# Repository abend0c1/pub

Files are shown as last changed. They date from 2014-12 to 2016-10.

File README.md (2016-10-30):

PUB! Programmable USB Button
============================
Program a button to send keystrokes to your computer

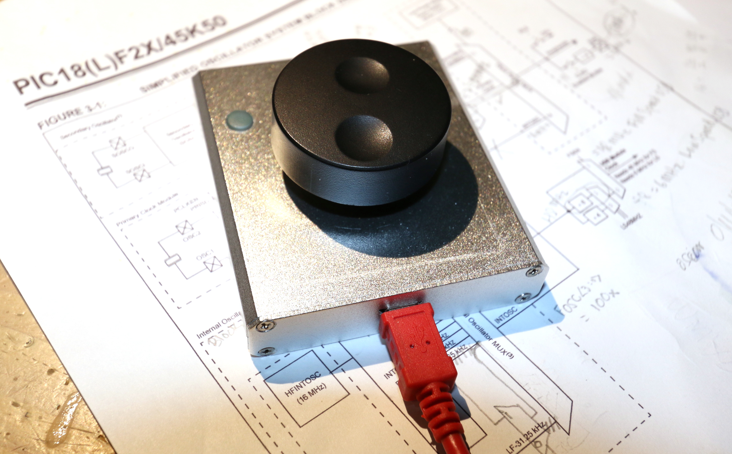
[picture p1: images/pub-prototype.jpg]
prototype


PUB! is a Programmable USB Button on which you can program a sequence of keystrokes. When you press the button those keystrokes are "replayed" over a USB connection.

The button (really a rotary encoder with a built-in push button switch) is programmed using an innovative and slightly quirky interface that does not require any custom software to be installed on your computer. All you need is a text editor like Notepad or gedit.

Features
--------
- One-button design (a rotary encoder with a built in switch).
- Programmed by using an ordinary text editor as a display (for example, gedit on Linux, or Notepad on Windows).
- Up to 127 keystrokes can be recorded and played back.
- Support for conditional logic. For example, Compare to value, Jump on zero, etc.
- Support for 256 x 8-bit "registers" to record state.
- Support for basic arithmetic. Add, subtract, etc.
- Can send USB System Control codes (Power off, sleep, wake) to your PC
- Can send USB Consumer Device functions (e.g. Mute, Play, Pause, Stop, etc.)
- Requires NO drivers (or custom software) for Windows/Linux etc

Futures
-------
The possibilities are fairly broad including:
- Using a Bluetooth module to detect proximity of the button owner's mobile phone so that the USB button is only enabled when its owner is near.
- Addition of an external EEPROM for extra keystroke capacity.
- The one-button user interface could be improved to make it easier to use.

Construction
------------

See http://www.instructables.com/id/PUB-Programmable-USB-Button/

How To Use
----------
### You want to program your password onto the PUB! button
  - Open a text editing program (for example, gedit or Notepad) and make sure it has keyboard focus
  - Plug PUB! into a host USB port
  - By default it is in RUN mode, so press and hold the rotary encoder knob for more than 1 second to switch to PROGRAM mode. It will display in your text editor:

          PUB! Programmable USB Button v0.93
          Main:   Turn=Select, Press=OK, Press+Turn=Set At, Press+Hold=Exit
             0    Set Keystroke at 00
          At Code Action

  - Press the rotary knob to set a keystroke. It will display:

          PUB! Programmable USB Button v0.93
          Key:    Turn=Select, Press+Turn=Modify, Press=OK, Press+Hold=Return
          00 0004 a
          At Code Action

  - Turn the rotary knob to choose the first letter of your password (say c) and then press the knob to add it to the list of actions:

          PUB! Programmable USB Button v0.93
          Key:    Turn=Select, Press+Turn=Modify, Press=OK, Press+Hold=Return
          01 0006 c
          At Code Action
          00 0006 c

  - Continue choosing and adding the remaining letters (say, a and t):

          PUB! Programmable USB Button v0.93
          Key:    Turn=Select, Press+Turn=Modify, Press=OK, Press+Hold=Return
          03 0017 t
          At Code Action
          00 0006 c
          01 0004 a
          02 0017 t

  - Press and hold the rotary knob to Return to the main menu:

          PUB! Programmable USB Button v0.93
          Main:   Turn=Select, Press=OK, Press+Turn=Set At, Press+Hold=Exit
             0    Set Keystroke at 03
          At Code Action
          00 0006 c
          01 0004 a
          02 0017 t

  - Rotate the knob until "Do Local Function" is displayed:

          PUB! Programmable USB Button v0.93
          Main:   Turn=Select, Press=OK, Press+Turn=Set At, Press+Hold=Exit
             0    Do Local Function at 03
          At Code Action
          00 0006 c
          01 0004 a
          02 0017 t

  - Press the knob to enter the "Do" menu:

            PUB! Programmable USB Button v0.93
            Do:     Turn=Modify, Press=OK, Press+Turn=Set At, Press+Hold=Exit
               0    Delete action at 00
            At Code Action
            00 0006 c
            01 0004 a
            02 0017 t

  - Press-and-rotate the knob anticlockwise until "Save to EEPROM" is displayed:

          PUB! Programmable USB Button v0.93
          Do:     Turn=Modify, Press+Turn=Select, Press=OK, Press+Hold=Return
                  Save to EEPROM
          At Code Action
          00 0006 c
          01 0004 a
          02 0017 t

  - Press the knob to save "cat" to the EEPROM

          Saved in EEPROM

  - The device is now in RUN mode. Press the knob to "play" the recorded sequence:

          cat

### An example of some conditional logic

  - Enter the following program into the PUB! device:

          At Code Action
          00 E005 Let W = 05
          01 E200 Put W in R00
          02 0006 c
          03 0004 a
          04 0017 t
          05 002C Space
          06 E500 Say R00
          07 0028 Enter
          08 EF01 Wait 1 sec
          09 E801 Let W = W - 01
          0A F701 Jump if Not Zero to 01

  - Now when you press the knob in run mode you should see the following displayed (1 second wait between lines):

          cat 05
          cat 04
          cat 03
          cat 02
          cat 01

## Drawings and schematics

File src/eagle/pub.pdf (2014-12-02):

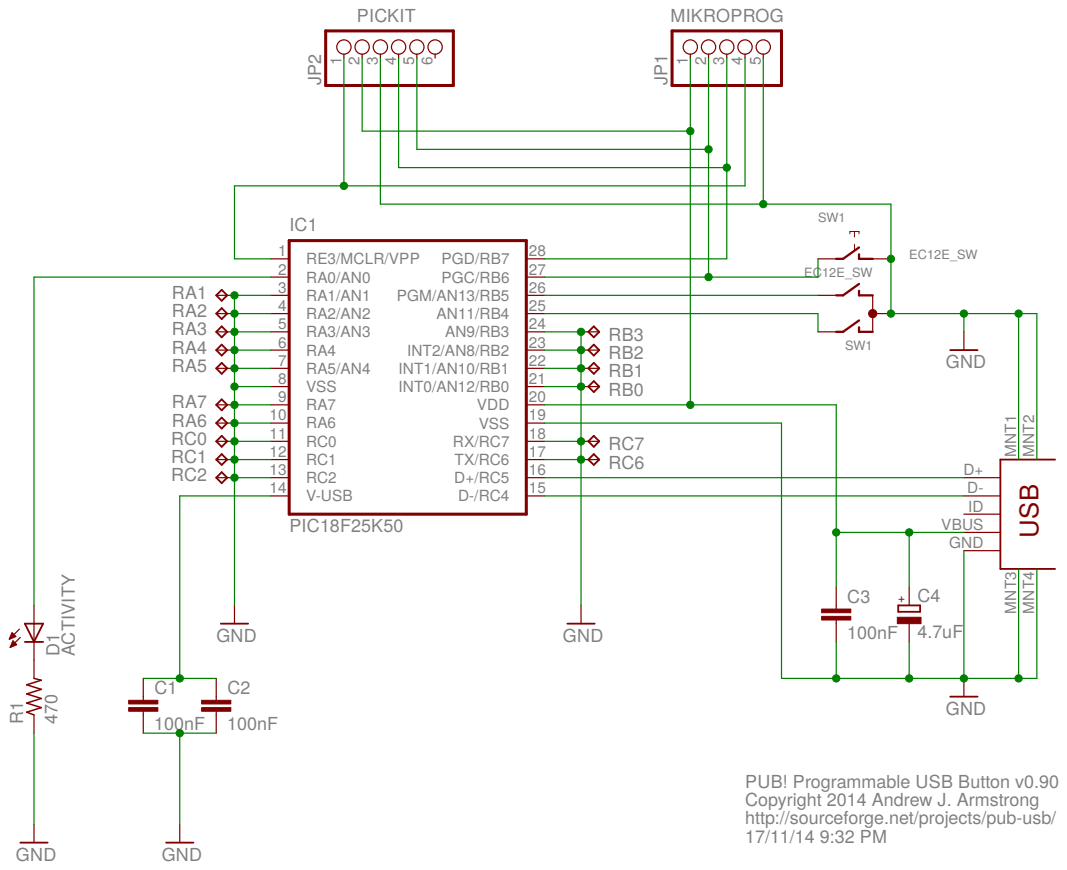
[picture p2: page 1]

PUB! Programmable USB Button v0.90
Copyright 2014 Andrew J. Armstrong
http://sourceforge.net/projects/pub-usb/

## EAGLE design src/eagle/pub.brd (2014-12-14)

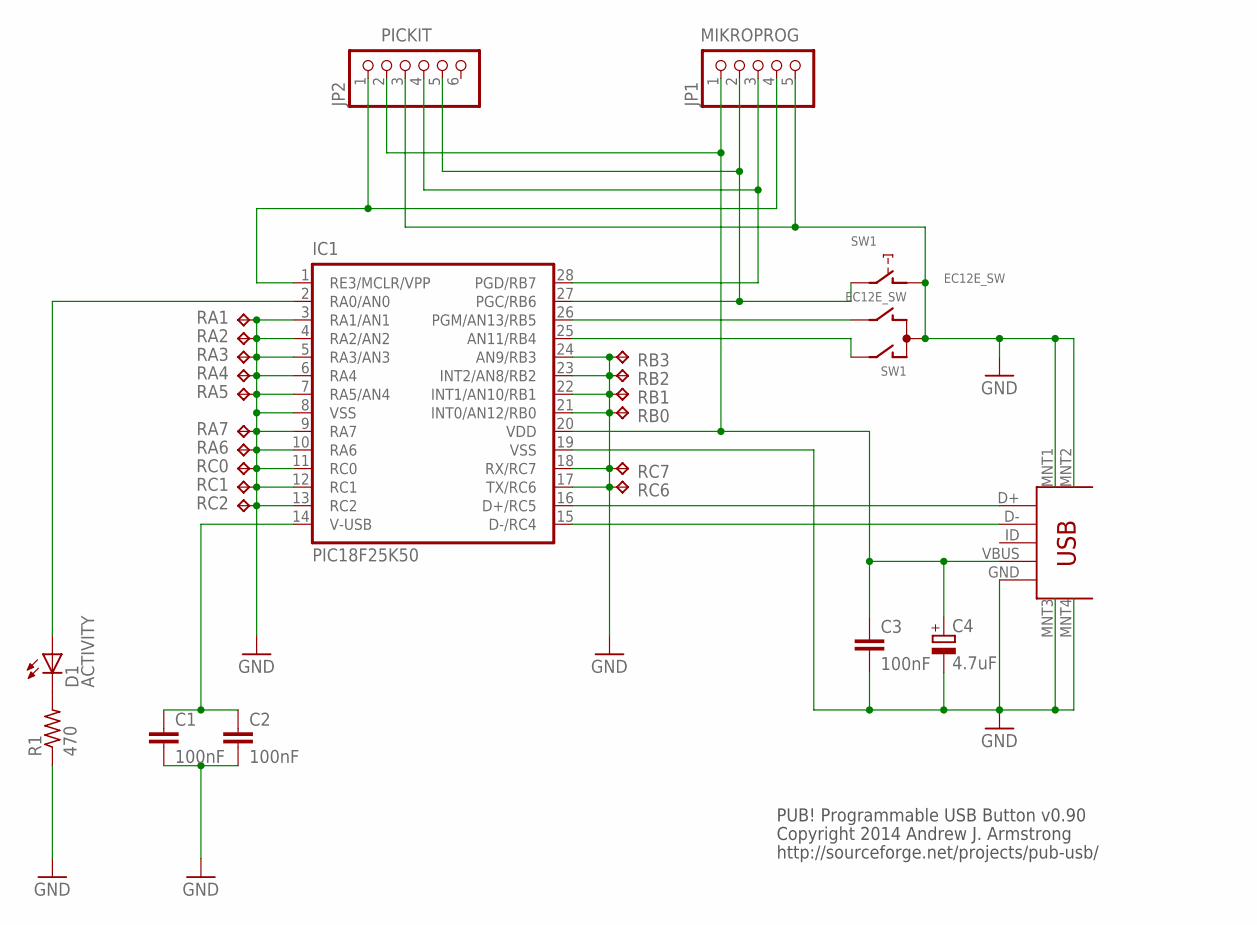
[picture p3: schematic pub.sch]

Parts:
C1, C2, C3: 100nF; C0805
C4: 4.7uF; SMC_A
D1: ACTIVITY; SML1206
IC1: PIC18F25K50; SO28W
JP1: MIKROPROG; 1X05/90
JP2: PICKIT; 1X06/90
JP3: USB-MINIB-5PIN; USB-MINIB
R1: 470; M1206
RA1, RA2, RA3, RA4, RA5, RA6, RA7: TPB1,27; B1,27
RB0, RB1, RB2, RB3: TPB1,27; B1,27
RC0, RC1, RC2, RC6, RC7: TPB1,27; B1,27
SW1: EC12E_SW; ALPS_EC12E_SW

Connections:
GND: C1.2, C2.2, C3.2, C4.-, IC1.3 (RA1/AN1), IC1.4 (RA2/AN2), IC1.5 (RA3/AN3), IC1.6 (RA4), IC1.7 (RA5/AN4), IC1.8 (VSS), IC1.9 (RA7), IC1.10 (RA6), IC1.11 (RC0), IC1.12 (RC1), IC1.13 (RC2), IC1.17 (TX/RC6), IC1.18 (RX/RC7), IC1.19 (VSS), IC1.21 (INT0/AN12/RB0), IC1.22 (INT1/AN10/RB1), IC1.23 (INT2/AN8/RB2), IC1.24 (AN9/RB3), JP1.5, JP2.3, JP3.GND, JP3.MNT1, JP3.MNT2, JP3.MNT3, JP3.MNT4, R1.1, RA1.TP, RA2.TP, RA3.TP, RA4.TP, RA5.TP, RA6.TP, RA7.TP, RB0.TP, RB1.TP, RB2.TP, RB3.TP, RC0.TP, RC1.TP, RC2.TP, RC6.TP, RC7.TP, SW1.C, SW1.D (1)
unnamed: IC1.26 (PGM/AN13/RB5), SW1.B
unnamed: IC1.25 (AN11/RB4), SW1.A
unnamed: C1.1, C2.1, IC1.14 (V-USB)
unnamed: D1.A, IC1.2 (RA0/AN0)
unnamed: IC1.16 (D+/RC5), JP3.D+
unnamed: IC1.15 (D-/RC4), JP3.D-
unnamed: C3.1, C4.+, IC1.20 (VDD), JP1.1, JP2.2, JP3.VBUS
unnamed: IC1.27 (PGC/RB6), JP1.2, JP2.5, SW1.E (2)
unnamed: IC1.28 (PGD/RB7), JP1.3, JP2.4
unnamed: IC1.1 (RE3/MCLR/VPP), JP1.4, JP2.1
unnamed: D1.C, R1.2

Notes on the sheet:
Copyright 2014 Andrew J. Armstrong
http://sourceforge.net/projects/pub-usb/
PUB! Programmable USB Button v0.90

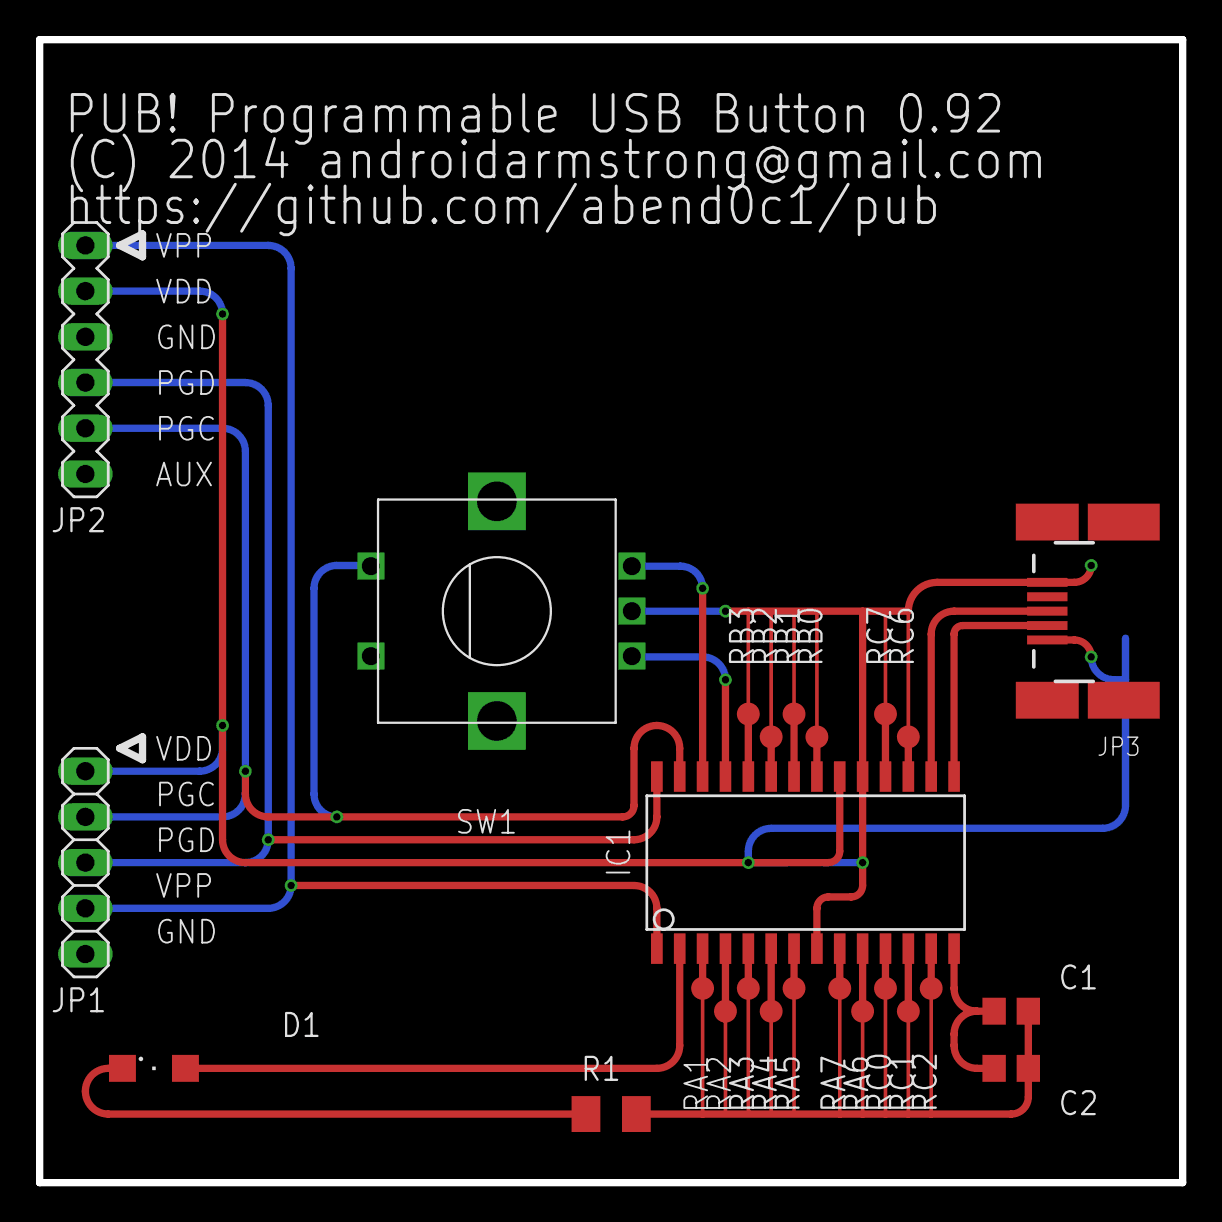
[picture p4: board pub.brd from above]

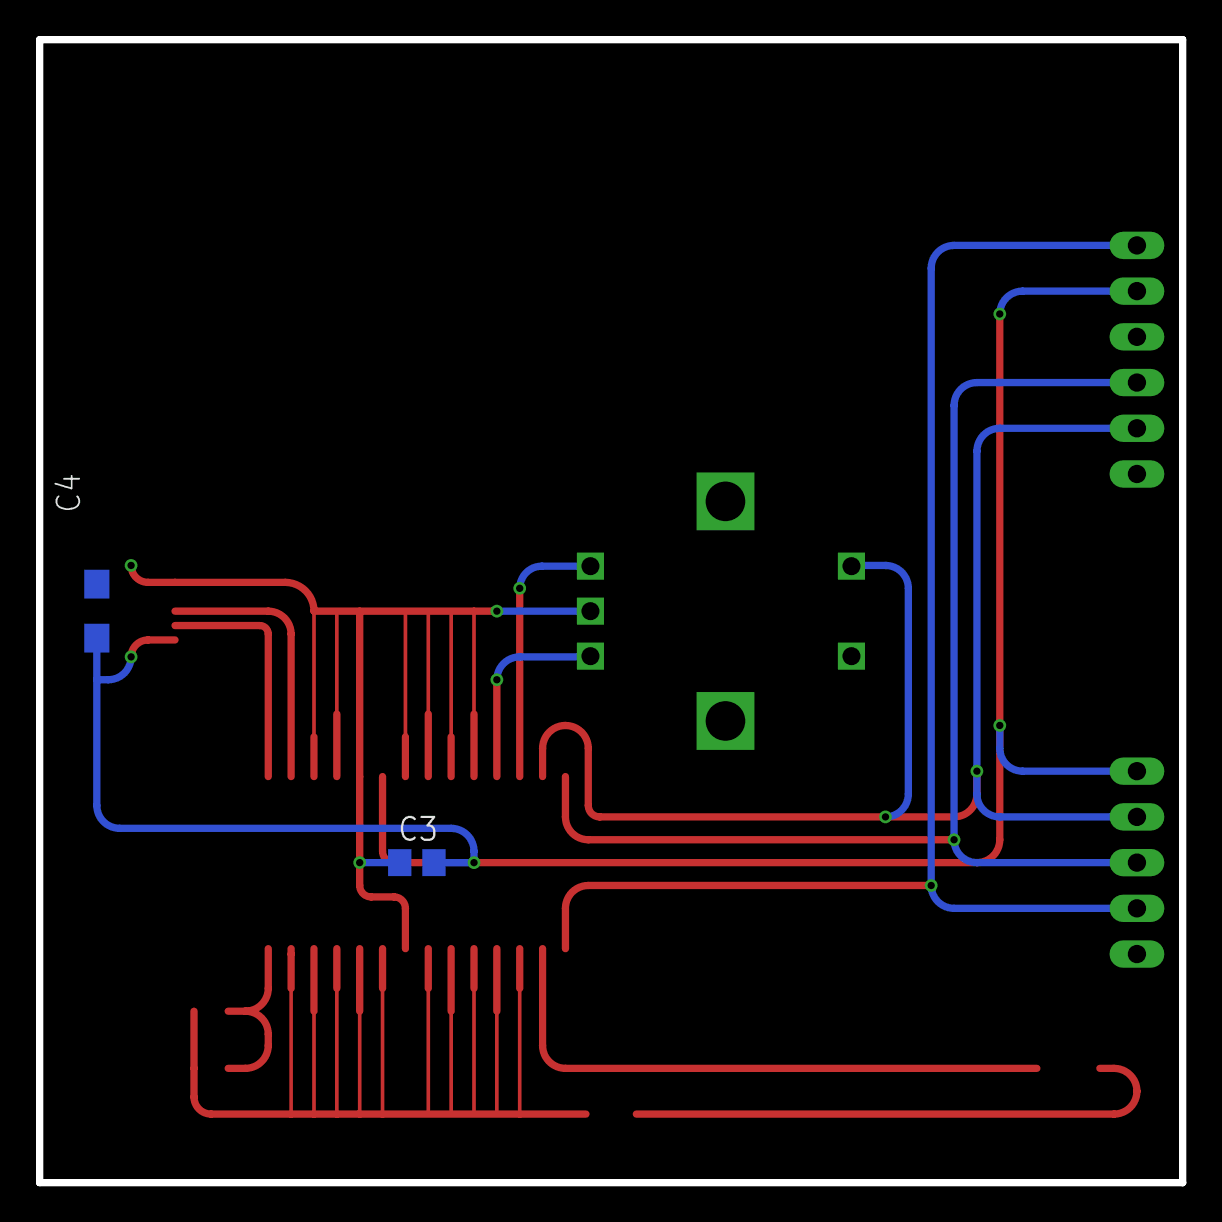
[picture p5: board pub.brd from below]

Board: 2 copper layers, 63.5 x 63.5 mm, 28 parts (2 on the bottom side), 12 nets.

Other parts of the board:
U$1: LIGHTGUIDE

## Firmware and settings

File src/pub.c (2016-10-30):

/*
  PUB! Programmable USB Button
  Copyright (C) 2014 Andrew J. Armstrong

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
  You should have received a copy of the GNU General Public License
  along with this program; if not, write to the Free Software
  Foundation, Inc., 59 Temple Place, Suite 330, Boston, MA
  02111-1307  USA

  Author:
  Andrew J. Armstrong <androidarmstrong@gmail.com>

*/

/*
-------------------------------------------------------------------------------

NAME     - PUB! Programmable USB Button

FUNCTION - This is a programmable button on which you can record a sequence of
           keystrokes (and/or other USB functions) and then play that sequence
           back when you press it.

FEATURES - 1. A single rotary encoder knob (with push switch) is the only input.
           2. Can record and replay up to 127 keystrokes (or other "actions").
           3. Absolutely NO HOST DRIVERS required.

PIN USAGE -                     PIC18F25K50
                           .------------------.                       .--IOC
            MCLR       --> | RE3  1    28 RB7 | <-- PGD               ||
            LED        <-- | RA0  2    27 RB6 | <-- PGC, Rotary button||
                       <-- | RA1  3    26 RB5 | <-- Rotary B          || PORTB
                       <-- | RA2  4    25 RB4 | <-- Rotary A          || Weak
                       <-- | RA3  5    24 RB3 | <--                    | Pullups
                       <-- | RA4  6    23 RB2 | <--                    | Enabled
                       <-- | RA5  7    22 RB1 | <--                    |
            Ground     --- | VSS  8    21 RB0 | <--                    |
            n/c        --- | RA7  9    20 VDD | --- +5V
                       <-- | RA6  10   19 VSS | --- Ground
                       <-- | RC0  11   18 RC7 | --> RX
                       <-- | RC1  12   17 RC6 | --> TX
                       <-- | RC2  13   16 RC5 | <-> USB D+
            2 x 100 nF --- | VUSB 14   15 RC4 | <-> USB D-
                           '------------------'

            Rotary Encoder with switch (e.g. ALPS EC11K0924401):

                            .-------.
             Rotary A   <-- |A     D|--> Rotary button
             Ground     <-- |C  o / |
             Rotary B   <-- |B     E|--> Ground
                            '-------'

CONFIG    - The PIC18F25K50 configuration fuses should be set as follows (items
            marked with '*' are essential for this program to operate correctly):

            CONFIG1L 2B 00101011
                          1      = *LS48MHZ: System clock is expected at 48 MHz, FS/LS USB clock divide-by is set to 8
                           01    = *CPUDIV: CPU system clock (48 MHz) divided by 2 (= 24 MHZ)
                             0   =  Unimplemented
                              x  =  CFGPLLEN: (ignored, set dynamically)
                               x =  PLLSEL: (ignored, set dynamically)
            CONFIG1H 28 00101000
                        0        =  IESO: Oscillator Switchover mode disabled
                         0       =  FCMEN: Fail-Safe Clock Monitor disabled
                          1      = *PCLKEN: Primary Clock is always enabled
                           0     =  Unimplemented
                            1000 = *FOSC: Internal oscillator block
            CONFIG2L 5F 01011111
                        0        =  Unimplemented
                         1       =  LPBOR: Low-Power Brown-out Reset disabled
                          0      =  Unimplemented
                           11    =  BORV: VBOR set to 1.9V nominal
                             11  =  BOREN: Brown-out Reset enabled in hardware only (SBOREN is disabled)
                               1 =  PWRTEN: Power-up Timer disabled
            CONFIG2H 3C 00111100
                        00       =  Unimplemented
                          1111   =  WDTPS: Watchdog Timer Postscale Select = 1:32768
                              00 =  WDTEN: Watchdog Timer disabled in hardware, SWDTEN bit disabled
            CONFIG3L 00 00000000
                        00000000 =  Unimplemented
            CONFIG3H 53 01010000
                        0        = *MCLRE: RE3 input pin enabled; MCLR disabled
                         1       =  SDOMX: SDO is on RB3
                          0      =  Unimplemented
                           1     =  T3CMX: T3CKI is on RC0
                            00   =  Unimplemented
                              0  =  PDADEN: ANSELB<5:0> resets to 0, PORTB<4:0> pins are configured as digital I/O on Reset
                               0 =  CCP2MX: CCP2 input/output is multiplexed with RB3
            CONFIG4L 81 10000001 =  Default
            CONFIG5L 0F 00001111 =  Default
            CONFIG5H C0 11000000 =  Default
            CONFIG6L 0F 00001111 =  Default

OPERATION - The user interacts with the system via a digital encoder knob with
            a built-in switch and, when in PROGRAM mode, with a host-based text
            editor program than understands fairly standard editing control
            sequences.

            In RUN mode (the default mode when the device is plugged into a USB
            port) the user simply presses the rotary knob to cause the previously
            programmed sequence of keystrokes to be sent to the host over the
            connecting USB cable.

            If the user presses the knob down for more than about 3 seconds,
            then the device enters PROGRAM mode. The user must already
            have started and given focus to the above-mentioned text editor
            host application because this will be the means of communication
            with the user. If that is not done then the device will inject
            unwanted keystrokes into the application that currently has the
            keyboard focus.

            - Start a text editor program on the host computer and ensure it
              has keyboard focus.

            - Press and hold the rotary encoder to enter PROGRAM mode.
              The following prompt will be keyed into the text editor:

              PUB! Programmable USB Button vn.nn
              Main:   Turn=Select, Press=OK, Press+Turn=Set At, Press+Hold=Exit
                 0    Set Keystroke at 00

              At Code Action

            - Rotate the knob to choose between the available menu functions
              which are currently:

              Set Keystroke
              Set System Control function
              Set Consumer Device function
              Set Local Function (WAIT, GOTO etc)
              Save to EEPROM
              Redisplay
              Reload from EEPROM
              Delete Action

            - Press the knob to select the desired function. For example,
              Set Keystroke

            - Rotate the knob until the desired keystroke is displayed:

              00 0004 a

            - For "Set keystroke" you can choose a combination of keystroke
              modifiers (Ctl, Alt, Shift, or GUI) by pressing and holding the
              knob down while rotating it:

              00 0104 SHIFT+A

            - Press the knob to append the displayed keystroke to the list of
              keystrokes (or functions) to be recorded.

            - Select and append more keystrokes as required.

            - Press and hold the knob to return to the main menu.

            - Rotate the knob to choose the "Save to EEPROM" function.

            - Now when you press the knob the saved keystrokes will be replayed.





NOTES    - 1. The source code is written in MikroC Pro from mikroe.com


REFERENCE - USB Human Interface Device Usage Tables at:
            http://www.usb.org/developers/devclass_docs/Hut1_12v2.pdf

            USB Device Class Definition for Human Interface Devices (HID) at:
            http://www.usb.org/developers/devclass_docs/HID1_11.pdf

            USB 2.0 Specification at:
            http://www.usb.org/developers/docs/usb_20_101111.zip
            Specifically, the file in that zip archive called usb_20.pdf

AUTHORS  - Init Name                 Email
           ---- -------------------- ------------------------------------------
           AJA  Andrew J. Armstrong  androidarmstrong@gmail.com

CREDITS  - Rotary encoder logic based on code originally written by Ben Buxton.
           http://www.buxtronix.net/2011/10/rotary-encoders-done-properly.html


HISTORY  - Date     Ver   By  Reason (most recent at the top please)
           -------- ----- --- -------------------------------------------------
           20161030 0.93  AJA Detected the Caps Lock state
           20141130 0.92  AJA Added arithmetic and conditional jump instructions
           20141108 0.91  AJA Fixed PCB to match code. Rotary button on RB6
           20141012 0.90  AJA First published version
           20140817 0.10  AJA Initial development

-------------------------------------------------------------------------------
*/
#include <stdint.h>
#include <built_in.h>
#include "USBdsc.h"
#include "pub.h"

// Copies a text string from ROM into a RAM buffer (saves RAM)
char * _TEXT(const char * p)
{
  static char sText[70];
  char * q;
  for (q=&sText; *q++ = *p++; );
  return &sText;
}

const char * getKeyDescWithNoShift (uint8_t key) // Note: Literals returned as const are in ROM
{ // Keyboard key without SHIFT modifier key pressed
  if (key < ELEMENTS(UNSHIFTED_USB_DESC))
  {
    return UNSHIFTED_USB_DESC[key];
  }
  else
  {
    return "";
  }
}

const char * getKeyDescWithShift(uint8_t key) // Note: Literals returned as const are in ROM
{ // Keyboard key with SHIFT modifier key pressed
  if (key < ELEMENTS(SHIFTED_USB_DESC))
  {
    return SHIFTED_USB_DESC[key];
  }
  else
  {
    return "";
  }
}


const char * getUsageDesc (t_action * pAction) // Note: Literals returned as const are in ROM
{
  switch (pAction->key.page)
  {
    case PAGE_KEYBOARD:
      if (pAction->key.mod & MODIFIER_LEFTSHIFT)
      {
        const char * pKeyDescWithShift = getKeyDescWithShift(pAction->key.usage);
        if (*pKeyDescWithShift)
          return pKeyDescWithShift;
      }
      return getKeyDescWithNoShift(pAction->key.usage);

    case PAGE_SYSTEM_CONTROL:
      if (pAction->sys.usage < ELEMENTS(SYSTEM_CONTROL_DESC))
      {
        return SYSTEM_CONTROL_DESC[pAction->sys.usage];
      }
      else
        return "";

    case PAGE_CONSUMER_DEVICE:
      if (pAction->cons.usage < ELEMENTS(CONSUMER_DEVICE_DESC))
      {
        return CONSUMER_DEVICE_DESC[pAction->cons.usage];
      }
      else
        return "";
//  case 0x30:     // Reserved
//  case 0x40:     // Reserved
//  case 0x50:     // Reserved
//  case 0x60:     // Reserved
//  case 0x70:     // Reserved
//  case 0x90:     // Reserved
//  case 0x90:     // Reserved
//  case 0xA0:     // Reserved
//  case 0xB0:     // Reserved
//  case 0xC0:     // Reserved

    case PAGE_DO:
      switch (pAction->key.mod)
      {
        case DO_DELETE:
          return "Delete action";
        case DO_LOAD:
          return "Load from EEPROM";
        case DO_SAVE:
          return "Save to EEPROM";
        case DO_REDISPLAY:
          return "Redisplay";
        default:
          return "";
      }

    case PAGE_EXECUTE:
      switch (pAction->key.mod)
      {
        case EXECUTE_SET:
          return "Let W = ";
        case EXECUTE_GET:
          return "Get W from R";
        case EXECUTE_PUT:
          return "Put W in R";
        case EXECUTE_COMPARE_IMMEDIATE:
          return "Compare W to ";
        case EXECUTE_COMPARE:
          return "Compare W to R";
        case EXECUTE_SAY:
          return "Say R";
        case EXECUTE_FORMAT:
          return "Say in ";
        case EXECUTE_ADD_IMMEDIATE:
          return "Let W = W + ";
        case EXECUTE_SUB_IMMEDIATE:
          return "Let W = W - ";
        case EXECUTE_CLEAR:
          return "Clear memory to ";
        case EXECUTE_ADD:
          return "Let W = W + R";
        case EXECUTE_SUB:
          return "Let W = W - R";
        case EXECUTE_MUL:
          return "Let W = W x R";
        case EXECUTE_DIV:
          return "Let W = W / R";
        case EXECUTE_WAIT_MS:
          return "Wait "; // milliseconds
        case EXECUTE_WAIT_SEC:
          return "Wait "; // seconds
        default:
          return "";
      }

    case PAGE_JUMP:
      switch (pAction->key.mod)
      {
        case JUMP_RELATIVE:
          return "Jump Relative";
        case JUMP_IF_CARRY:
          return "Jump if Carry";
        case JUMP_IF_HIGH:
          return "Jump if High";
        case JUMP_IF_HIGH_OR_CARRY:
          return "Jump if High or Carry";
        case JUMP_IF_LOW:
          return "Jump if Low";
        case JUMP_IF_LOW_OR_CARRY:
          return "Jump if Low or Carry";
        case JUMP_IF_NOT_ZERO_OR_CARRY:
          return "Jump if Not Zero or Carry";
        case JUMP_IF_NOT_ZERO:
          return "Jump if Not Zero";
        case JUMP_IF_ZERO:
          return "Jump if Zero";
        case JUMP_IF_ZERO_OR_CARRY:
          return "Jump if Zero or Carry";
        case JUMP_IF_NOT_LOW_OR_CARRY:
          return "Jump if Not Low or Carry";
        case JUMP_IF_NOT_LOW:
          return "Jump if Not Low";
        case JUMP_IF_ZERO_OR_LOW:
          return "Jump if Zero or Low";
        case JUMP_IF_NOT_HIGH:
          return "Jump if Not High";
        case JUMP_IF_NOT_CARRY:
          return "Jump if Not Carry";
        case JUMP:
          return "Jump";
        default:
          break;
      }

    default:
      return "";
  }
}

void toPrintableHex(uint8_t c, char * p)
{
  static const char HEX[] = "0123456789ABCDEF";
  *p++ = HEX[(c & 0xF0) >> 4];
  *p++ = HEX[(c & 0x0F)     ];
  *p   = '\0';
}

void adjustShiftModifier ()
{
  if (usbToHost[3] >= USB_KEY_A && usbToHost[3] <= USB_KEY_Z)  // Handle SHIFT for alphabetics
  {
    // If the user wants SHIFT+A to be sent to the host, then it is reasonable
    // to expect it to be interpreted by the host as an uppercase "A". But, if
    // the Caps Lock indicator is on, SHIFT+A would result in the host seeing
    // it as a lowercase "a"...UNLESS we can choose to set the SHIFT modifier
    // depending on the current state of the Caps Lock LED indicator.

    // Truth table:
    // input       input           output
    // modifiers   Caps Lock       modifiers
    // SHIFT bit   LED light       SHIFT bit   Result at host
    // ---------   ---------  -->  ---------   --------------
    //     0           0               0             a
    //     0           1               1             a
    //     1           0               1             A
    //     1           1               0             A
    // This is a classic Exclusive-OR truth table, from which we can code:

    if ((usbToHost[1] & SHIFT) != leds.bits.CapsLock) // Logical Exclusive-OR
      usbToHost[1] |= SHIFT;              // SHIFT modifier bit = 1
    else
      usbToHost[1] &= ~SHIFT;             // SHIFT modifier bit = 0
  }
}


void playSystemControlCommand(t_action * pAction)
{
  if (!bUSBReady) return;
  usbToHost[0] = REPORT_ID_SYSTEM_CONTROL;  // Report Id = System Control
  usbToHost[1] = pAction->sys.usage;        // Function requested
  while(!HID_Write(&usbToHost, 2));         // Copy to USB buffer and try to send
  usbToHost[1] = 0;                         // No function requested anymore
  while(!HID_Write(&usbToHost, 2));         // Copy to USB buffer and try to send
}

void playConsumerDeviceCommand(t_action * pAction)
{
  if (!bUSBReady) return;
  usbToHost[0] = REPORT_ID_CONSUMER_DEVICE; // Report Id = Consumer Device
  usbToHost[1] = pAction->cons.usage;       // Function requested (low byte)
  usbToHost[2] = pAction->cons.usage >> 8;  // Function requested (high byte)
  while(!HID_Write(&usbToHost, 3));         // Copy to USB buffer and try to send
  usbToHost[1] = 0;                         // Function requested low byte
  usbToHost[2] = 0;                         // Function requested high byte
  while(!HID_Write(&usbToHost, 3));         // Copy to USB buffer and try to send
}

void sayNoKeyPressed()
{
  usbToHost[0] = REPORT_ID_KEYBOARD;        // Report Id = Keyboard
  usbToHost[1] = 0;                         // No modifiers now
  usbToHost[3] = 0;                         // No key pressed now
  while(!HID_Write(&usbToHost, 4));         // Copy to USB buffer and try to send
}

void playKeystroke(t_action * pAction)
{
  if (!bUSBReady) return;
  if (usbToHost[0] == REPORT_ID_KEYBOARD && // If new keystroke is the same as the last one
      usbToHost[1] == pAction->key.mod   &&
      usbToHost[3] == pAction->key.usage)
  {
    sayNoKeyPressed();                      // Release the key before sending it again
  }
  usbToHost[0] = REPORT_ID_KEYBOARD;        // Report Id = Keyboard
  usbToHost[1] = pAction->key.mod;          // Ctrl/Alt/Shift modifiers
  usbToHost[2] = 0;                         // Reserved for OEM
  usbToHost[3] = pAction->key.usage;        // Key pressed
  adjustShiftModifier();                    // Adjust SHIFT for alphabetics
  while(!HID_Write(&usbToHost, 4));         // Copy to USB buffer and try to send
  usbToHost[1] = pAction->key.mod;          // Reset modifiers to what was requested
}

void say(uint8_t * p)
{
  uint8_t c;
  t_action action;

  while (*p)
  {
    if (*p < sizeof(ASCII_to_USB))
    {
      c = ASCII_to_USB[*p]; // Top bit on means capitalise with Left Shift
    }
    else
    {
      c = SPACE; // Replace invalid ASCII character with a space
    }
    if (c & 0b10000000) // If SHIFT key needed
    {
      action.key.mod = MODIFIER_LEFTSHIFT;
      action.key.usage = c & 0b01111111;
    }
    else
    {
      action.key.mod = 0;
      action.key.usage = c;
    }
    playKeystroke(&action);
    p++;
  }
  sayNoKeyPressed(); // Release key otherwise the host will think the last key is still being pressed
}

void sayConst(const uint8_t * p)
{
  say(_TEXT(p));
}

void sayModifiers(t_keyboardAction * pAction)
{
  if (pAction->mod & MODIFIER_LEFTGUI)     sayConst("GUI+");
  if (pAction->mod & MODIFIER_LEFTCTL)     sayConst("CTL+");
  if (pAction->mod & MODIFIER_LEFTALT)     sayConst("ALT+");
  if (pAction->mod & MODIFIER_LEFTSHIFT)   sayConst("SHIFT+");
}

void sayChar(uint8_t c)
{
  char sString[2];
  sString[0] = c;
  sString[1] = '\0';
  say(sString);
}

void sayHex(uint8_t c)
{
  char xString[3];
  toPrintableHex(c, xString);
  say(xString);
}

void sayDec(uint8_t c)
{
  char * p;
  char sString[4]; // "nnn"
  ByteToStr(c, &sString);
  for (p=&sString; *p == ' '; p++);  // Find first non-blank
  say(p);
}

void saySignedDec(int8_t c)
{
  char * p;
  char sString[4]; // "nnn"
  ShortToStr(c, &sString);
  for (p=&sString; *p == ' '; p++);  // Find first non-blank
  say(p);
}

void sayKey(uint8_t modifiers, uint8_t key)
{
  if (!bUSBReady) return;
  usbToHost[0] = REPORT_ID_KEYBOARD;      // Report Id = Keyboard
  usbToHost[1] = modifiers;               // Ctrl/Alt/Shift modifiers
  usbToHost[2] = 0;                       // Reserved for OEM
  usbToHost[3] = key;                     // Key pressed
  adjustShiftModifier();                  // Adjust SHIFT for alphabetics
  while(!HID_Write(&usbToHost, 4));       // Copy to USB buffer and try to send
  sayNoKeyPressed();                      // Release key
}

void enableUSB()
{
  uint8_t i;

  usbToHost[0] = REPORT_ID_KEYBOARD;     // Report Id = Keyboard
  usbToHost[1] = 0;                      // No modifiers
  usbToHost[2] = 0;                      // Reserved for OEM
  usbToHost[3] = 0;                      // No key pressed
  bUSBReady = FALSE;
  while (!bUSBReady)
  {
    HID_Enable(&usbFromHost, &usbToHost);
    for (i=0; !bUSBReady && i < 50; i++) // Keep trying for up to 50 x 100 ms = 5 seconds
    {
      Delay_ms(100);
      ACTIVITY_LED = ON;                         // LED will be turned off by the next timer interrupt
      bUSBReady = HID_Write(&usbToHost, 4) != 0; // Copy to USB buffer and try to send
    }
    if (!bUSBReady)
    {
      HID_Disable();
      Delay_ms(5000);
    }
  }
  Delay_ms(250);
}

void disableUSB()
{
  HID_Disable();
  bUSBReady = FALSE;
}

void wait()
{
  Delay_ms(20);
}

void saveInEEPROM()
{
  t_action * p;
  uint8_t addr;
  uint8_t  i;

  EEPROM_Write(0, nActionFocus);   // Save currently focussed action in byte 0
  EEPROM_Write(1, nAction);        // Save number of actions
  p = &aAction[0];
  addr = 2;
  for (i = 0; i < nAction; i++, p++)
  {
    EEPROM_Write(addr++, Hi(p->action));
    EEPROM_Write(addr++, Lo(p->action));
  }
}
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
void main()
{
  uint8_t nRead;
  Prolog();
  while (1)
  {
    if (HID_Read() == 2 && usbFromHost[0] == REPORT_ID_KEYBOARD)   // If a host LED indication response is available
    {
      leds.byte = usbFromHost[1];   // Remember the most recent LED status change
    }
    bProgramMode ? programMode() : runMode();
  }
}

void interrupt()               // High priority interrupt service routine
{
  USB_Interrupt_Proc();        // Always give the USB module first opportunity to process

  if (IOCIF_bit)               // Interrupt On Change interrupt?
  {
    if (ROTARY_BUTTON_PRESSED)
    {
      bUserInterrupt = TRUE;
    }
    state = *(stateArray + ((state & STATE_MASK) << 2 | (ROTARY_B << 1 | ROTARY_A)));
    rotation |= state & EVENT_MASK; // Extract rotary event from encoder state
    IOCIF_bit = 0;             // Clear Interrupt On Change flag
  }
  if (TMR0IF_bit)              // Timer0 interrupt? (22.9 times/second)
  {
    ACTIVITY_LED = OFF;        // Always turn the LED off after at most 44 ms
    TMR0IF_bit = 0;            // Clear the Timer0 interrupt flag
  }
  if (TMR3IF_bit)              // Timer3 interrupt? (22.9 times/second)
  {
    nRemainingTimerTicks--;    // Decrement delay count
    TMR3IF_bit = 0;            // Clear the Timer3 interrupt flag
  }

}

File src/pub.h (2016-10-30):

#define VERSION "0.93"

#define OUTPUT        0
#define INPUT         1

#define ON            1
#define OFF           0

#define HIGH          1
#define LOW           0

#define ENABLE        1
#define DISABLE       0

#define TRUE  (1==1)
#define FALSE !TRUE

#define ELEMENTS(array) (sizeof(array)/sizeof(array[0]))
#define CLOCK_FREQUENCY       (__FOSC__ * 1000)
#define TIMER3_PRESCALER      8
#define INTERVAL_IN_SECONDS(n) (CLOCK_FREQUENCY / 4 / TIMER3_PRESCALER / 65536 * n)

#define INFO_LINE           2
#define SELECTION_LINE      3
#define START_ACTIONS_LINE  6

#define NONE  0b00000000
#define SHIFT 0b00000001
#define CTL   0b00000010
#define ALT   0b00000100
#define GUI   0b00001000

#define ROTATED     0b00000010
#define NOT_ROTATED 0b00000000
#define PRESSED     0b00000001
#define NOT_PRESSED 0b00000000

/*
#define USE_LAT

#ifdef USE_LAT
  #define ASSIGN_PIN(name,b) \
  sbit name               at LAT ## b ## _bit; \
  sbit name ## _Direction at TRIS ## b ## _bit;
#else
  #define ASSIGN_PIN(name,b) \
  sbit name               at R ## b ## _bit; \
  sbit name ## _Direction at TRIS ## b ## _bit;
#endif


ASSIGN_PIN(LCD_EN, B0)
ASSIGN_PIN(LCD_RS, B1)
ASSIGN_PIN(LCD_D4, B2)
ASSIGN_PIN(LCD_D5, B3)
ASSIGN_PIN(LCD_D6, B4)
ASSIGN_PIN(LCD_D7, B5)
*/

uint8_t MEMORY[256];   // Memory

uint8_t FORMAT;   // Format for SAY instruction
#define FORMAT_HEX  0
#define FORMAT_DEC  1
#define FORMAT_CHAR 2

uint8_t WRK;      // Working register

uint8_t CC;       // Condition Code
#define CC_Z 0x8
#define CC_M 0x4
#define CC_P 0x2
#define CC_O 0x1



typedef struct
{
  union
  {
    uint8_t byte;
    struct
    {
      LeftShift:1;      // .......1
      LeftControl:1;    // ......1.
      LeftAlt:1;        // .....1..
      LeftGUI:1;        // ....1...
      RightShift:1;     // ...1....
      RightControl:1;   // ..1.....
      RightAlt:1;       // .1......
      RightGUI:1;       // 1.......
    } bits;
  };
} t_keyModifiers;


typedef struct
{ // Keyboard:      // 0000mmmmuuuuuuuu
  uint8_t usage;    //         uuuuuuuu
  uint8_t mod:4;    //     mmmm
#define MODIFIER_LEFTSHIFT   0b0001
#define MODIFIER_LEFTCTL     0b0010
#define MODIFIER_LEFTALT     0b0100
#define MODIFIER_LEFTGUI     0b1000
  uint8_t page:4;   // 0000
} t_keyboardAction;


typedef struct
{ // Consumer Device: // 0001uuuuuuuuuuuu
  uint8_t usage:12;   //     uuuuuuuuuuuu
  uint8_t page:4;     // 0001
} t_consumerDeviceAction;

typedef struct
{ // System Control:  // 0010....uuuuuuuu
  uint8_t usage;      //         uuuuuuuu
  uint8_t :4;         //     ....
  uint8_t page:4;     // 0010
} t_systemControlAction;

typedef struct
{ // Instruction:   // 1110ccccoooooooo
  uint8_t operand;  //         oooooooo
  uint8_t opcode:4; //     cccc
  uint8_t page:4;   // 1110
} t_instAction;

typedef struct
{ // Jump:          // 1111mmmmaaaaaaaa
  uint8_t addr;     //         aaaaaaaa
  uint8_t mask:4;   //     mmmm
  uint8_t page:4;   // 1111
} t_jumpAction;

typedef union
{
  t_keyboardAction       key;   // 0000mmmmuuuuuuuu = 0x0muu
  t_consumerDeviceAction cons;  // 0001uuuuuuuuuuuu = 0x1uuu
  t_systemControlAction  sys;   // 0010....uuuuuuuu = 0x2.uu
  t_instAction           inst;  // 1110ccccoooooooo = 0xEcoo
  t_jumpAction           jump;  // 1111mmmmaaaaaaaa = 0xFmaa
  uint16_t               action;// ................ = 0x....
} t_action;

uint8_t nAction;          // Number of actions
uint8_t nActionFocus;   // Action with the current focus
t_action action;
t_action aAction[127];    // 127 x 2-byte actions + 2-byte header fills the onboard EEPROM

#define FOCUS_ON_PAGE  0
#define FOCUS_ON_USAGE 1
uint8_t focus = FOCUS_ON_PAGE;


volatile bit bUserInterrupt;
volatile int8_t rotation;  // 0 = no rotary event, +n = clockwise, -n = anticlockwise
volatile uint8_t nRemainingTimerTicks;


/*
    .---------------------------------------.
    |          REPORT_ID_KEYBOARD           | OUT: Report Id
    |---------------------------------------|
    |    |    |    |    |    |SCRL|CAPL|NUML| OUT: NumLock,CapsLock,ScrollLock - and 5 unused pad bits
    '---------------------------------------'
*/
typedef union
{
  uint8_t byte;
  struct
  {
    NumLock:1;      // xxxxxxx1
    CapsLock:1;     // xxxxxx1x
    ScrollLock:1;   // xxxxx1xx
    :5;             // Pad
  } bits;
} t_ledIndicators;


// Buttons (weak pullups are enabled so they read high when not pressed)

sbit ROTARY_A                   at RB5_bit;
sbit ROTARY_B                   at RB4_bit;
sbit ROTARY_BUTTON              at RB6_bit;
#define ROTARY_BUTTON_PRESSED   !ROTARY_BUTTON

#define ACTIVITY_LED          LATA0_bit

volatile uint8_t             cFlags;
#define bUSBReady            cFlags.B0
#define bProgramMode         cFlags.B1
#define bLongPress           cFlags.B2
#define bUserInterrupt       cFlags.B3

// USB buffers must be in USB RAM, hence the "absolute" specifier...
uint8_t BANK4_RESERVED_FOR_USB[256] absolute 0x400; // Prevent compiler from allocating
                                                    // RAM variables in Bank 4 because
                                                    // the USB hardware uses that bank.
                                                    // Refer to the PIC18F25K50 datasheet
                                                    // section "6.4.1 USB RAM" for more
                                                    // information.
uint8_t usbFromHost[1+1] absolute 0x500;  // Buffer for PIC <-- Host (ReportId + 1 byte)
uint8_t usbToHost[1+3]   absolute 0x508;  // Buffer for PIC --> Host (ReportId + 3 bytes)

t_ledIndicators leds;

union
{
  uint16_t xxyy;            // xxyy (xyy is changed by UP/DOWN buttons)
  struct
  {                         // This overlays the Little-Endian xxyy above
    uint8_t yy;             //   yy
    t_keyModifiers xx;      // xx   (x is changed by CTL/ATL/SHIFT buttons)
  } s;
} usbData;

#define PAGE_KEYBOARD              0x0

#define PAGE_SYSTEM_CONTROL        0x1

#define PAGE_CONSUMER_DEVICE       0x2

#define PAGE_DO                    0xD
  #define DO_DELETE                  0x0
  #define DO_REDISPLAY               0x1
  //      DO_                        0x2
  //      DO_                        0x3
  //      DO_                        0x4
  //      DO_                        0x5
  //      DO_                        0x6
  //      DO_                        0x7
  //      DO_                        0x8
  //      DO_                        0x9
  //      DO_                        0xA
  //      DO_                        0xB
  //      DO_                        0xC
  //      DO_                        0xD
  #define DO_LOAD                    0xE
  #define DO_SAVE                    0xF
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

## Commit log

2014-10-06 Initial version
    [passifier.cfg]
2014-10-06 Reworked delete action logic
    [passifier.c, passifier.h]
2014-10-07 Renamed project to PUB! (Programmable USB Button) Added code to save to/load from EEPROM
    [pub.cfg]
2014-10-11 Fixed the 'Delete action' function
    [pub.c, pub.h]
2014-10-11 Add debounce after button release
2014-10-12 Correct display of Consumer Device actions
    [pub.c]
2014-10-23 Added Eagle CAD schematic and board
    [pub.brd, pub.sch]
2014-10-25 Tweaked PCB slightly
    [pub.brd, pub.sch]
2014-10-26 Created gerber files for the PCB
    [pub.brd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]
2014-10-26 Added product name to the PCB
    [pub.brd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]
2014-10-26 Adjust text on PCB
    [pub.brd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]
2014-10-26 Use ITEAD Studio's DRC and CAM job to create the gerber files
    [pub.GBL, pub.GBO, pub.GBP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]
2014-10-27 Fixed unconnected trace on PCB. The ITEAD guys found it. I don't know how it missed that.
    [pub.brd]
2014-11-03 Reworked PCB layout and changed to vector fonts
    [pub.brd]
2014-11-09 Fixed PCB to match code. Rotary button on RB6
    [pub.brd, pub.sch]
2014-11-12 Updated gerber files for v0.91 PCB layout
    [pub.brd, pub.sch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]
2014-11-13 Fix key playback to handle sending the same keystroke consecutively
    [pub.c]
2014-11-15 Used Timer0 for LED blinking instead of Timer3
2014-11-15 Renamed LED to ACTIVITY_LED
2014-11-16 Update handling of playback interruption by user
2014-11-16 Fix the "user abort" button press logic.
    When the user requests to abort the playback by pressing the button
    the code now waits for any button press bouncing to subside, then
    it waits for the user to release the button, then waits for any
    button release bouncing to subside.
    [pub.c, pub.h]
2014-11-17 Fixed typo in PICKIT header.
    How did I not see it spelled as PICKKIT? Sheesh!
    [pub.brd, pub.sch]
2014-12-02 Added a PDF circuit diagram
2014-12-14 Updated PCB art
    [pub.brd]
2015-02-16 Added image of prototype to README.md
2016-10-30 Detected the state of the Caps Lock LED indicator.
    Prior this update, if you coded SHIFT+A then the host interpreted
    that as either uppercase "A" or lowercase "a" depending on the
    current setting of the CAPS LOCK status. Now SHIFT+A will always
    be interpreted by the host as uppercase "A" because the device
    knows whether the CAPS LOCK LED is on or not. If CAPS LOCK is
    on, then the SHIFT modifier is reset so that the "a" is interpreted
    by the host as "A".
    [pub.c, pub.h]

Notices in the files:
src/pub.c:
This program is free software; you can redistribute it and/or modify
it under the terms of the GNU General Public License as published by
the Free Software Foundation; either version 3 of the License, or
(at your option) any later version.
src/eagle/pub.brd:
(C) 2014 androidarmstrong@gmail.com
